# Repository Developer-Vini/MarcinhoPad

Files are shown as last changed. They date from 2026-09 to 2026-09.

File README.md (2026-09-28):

# MarcinhoPad

Custom macropad designed for the Hack Club Hackpad program.

## Overview

MarcinhoPad is a compact macro keyboard built around a Seeed XIAO RP2040. It features 6 mechanical switches, a rotary encoder for volume control, and an OLED display for visual feedback.

## Requirements Compliance

- MCU: Seeed XIAO RP2040 (through-hole)
- PCB: 2-layer, under 100mm x 100mm
- Case: 3D-printed only, fits within 200x200x100mm
- Inputs: 6 switches + 1 encoder (7 total, under 16 limit)
- Firmware: KMK (CircuitPython)

## Screenshots

### PCB
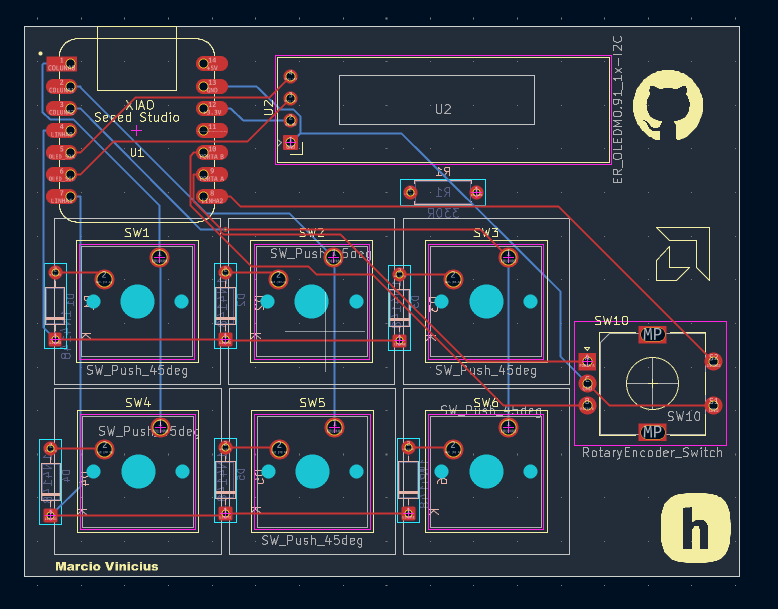
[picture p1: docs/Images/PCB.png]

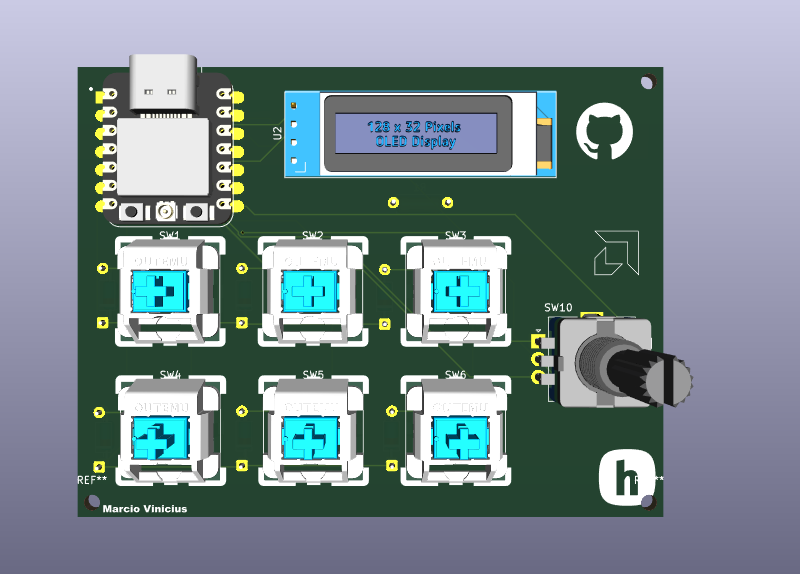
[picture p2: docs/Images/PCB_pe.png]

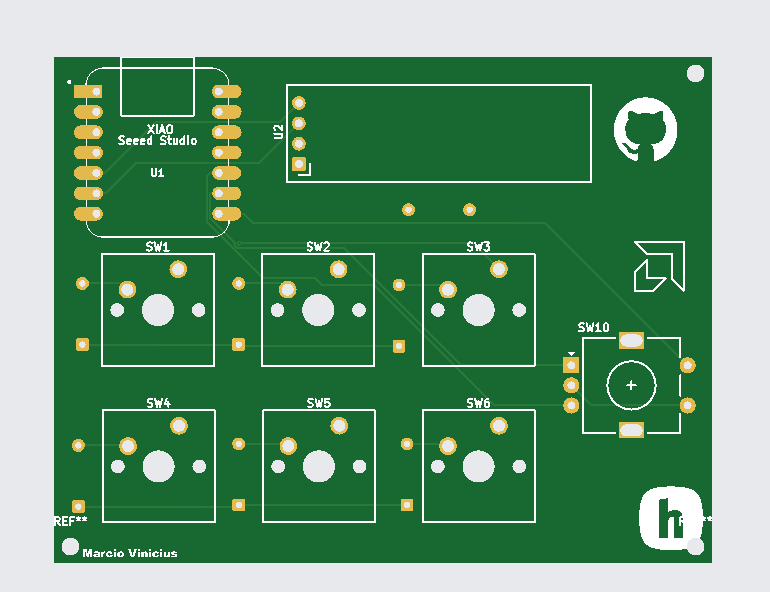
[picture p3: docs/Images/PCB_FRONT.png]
PCB_NOT

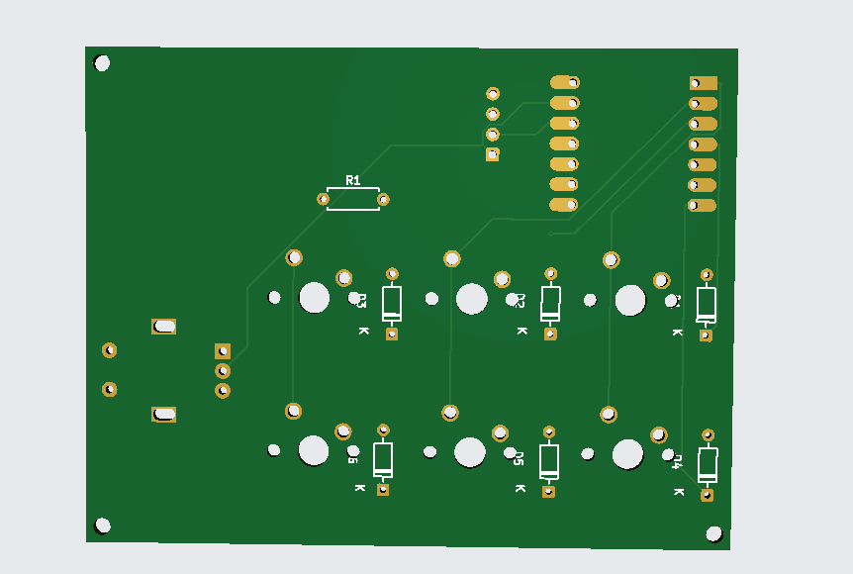
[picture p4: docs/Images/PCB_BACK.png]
PCB_BACK


### Schematic
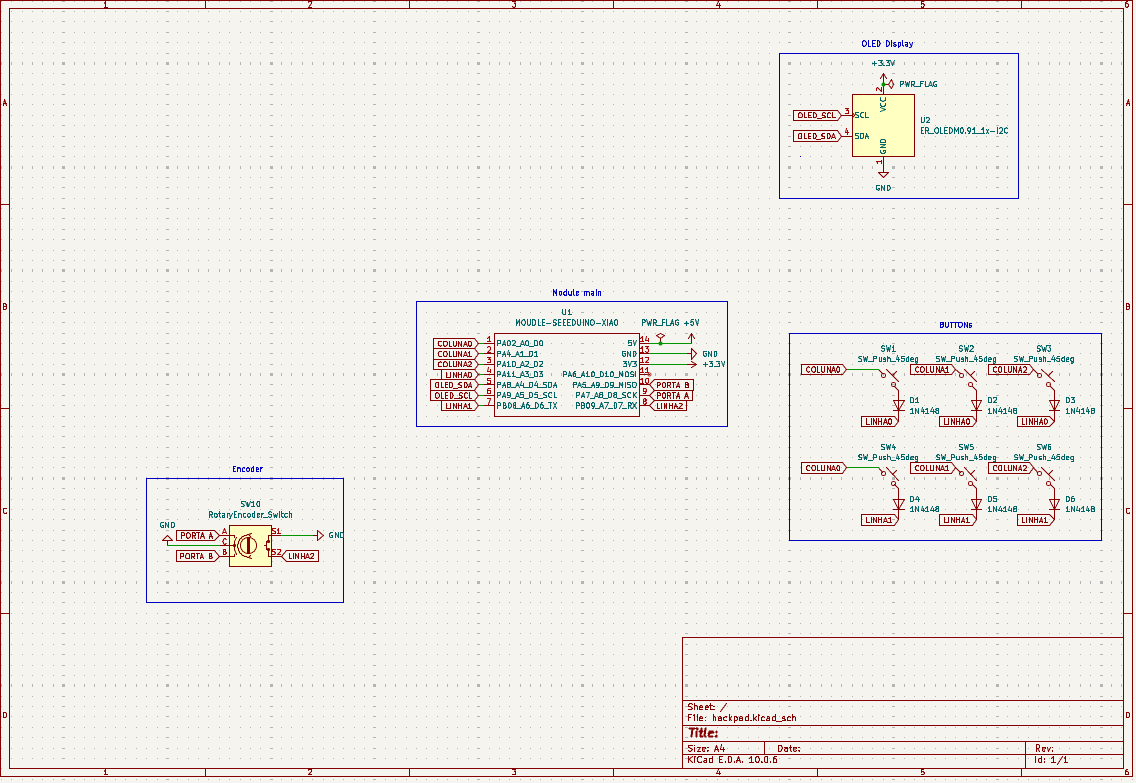
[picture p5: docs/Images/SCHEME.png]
Schematic


### Case
The case is 3D-printed in two parts (base + lid). See `production/case/` for STL files.

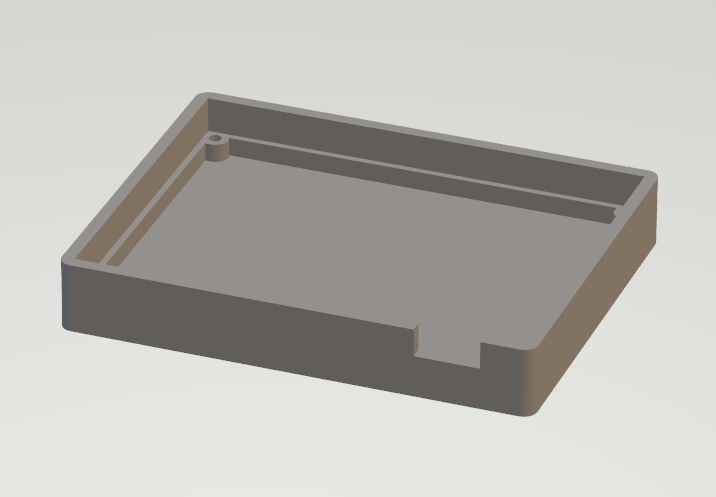
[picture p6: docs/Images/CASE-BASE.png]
BASE

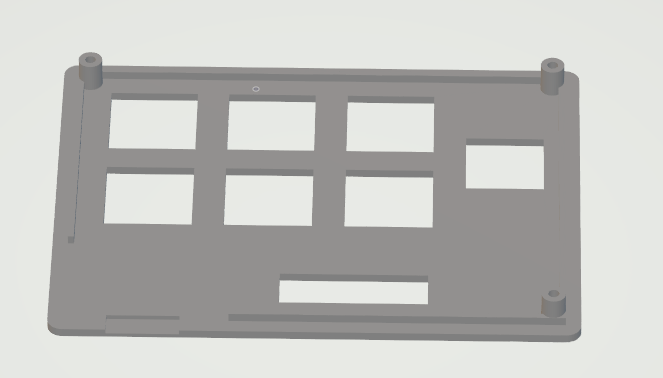
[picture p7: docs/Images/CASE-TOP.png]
TOPO


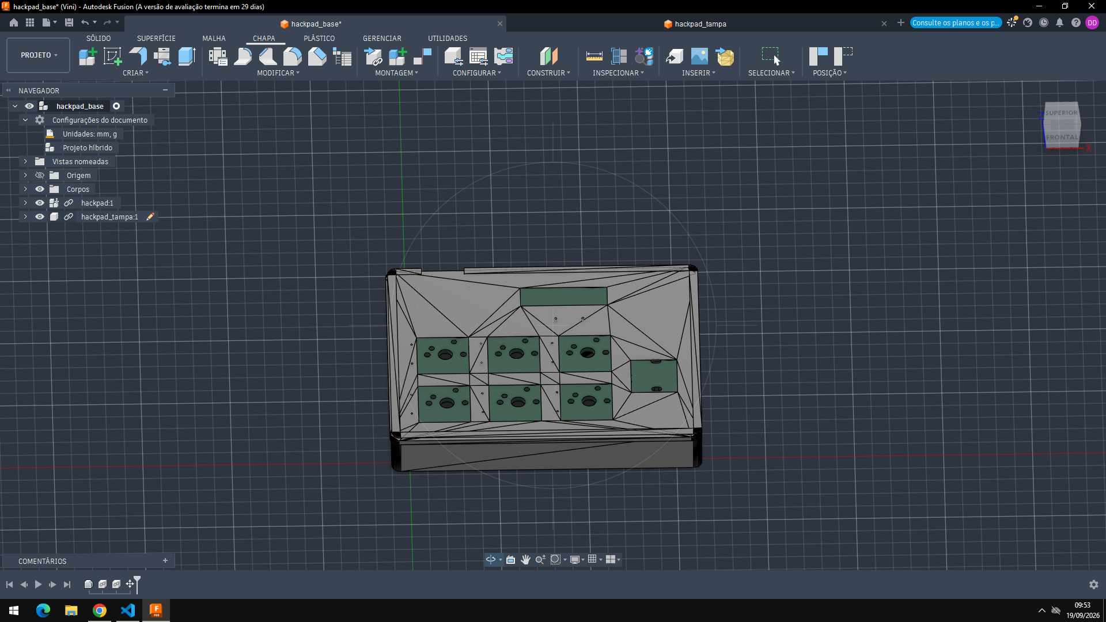
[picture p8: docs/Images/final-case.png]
FINAL-CASE


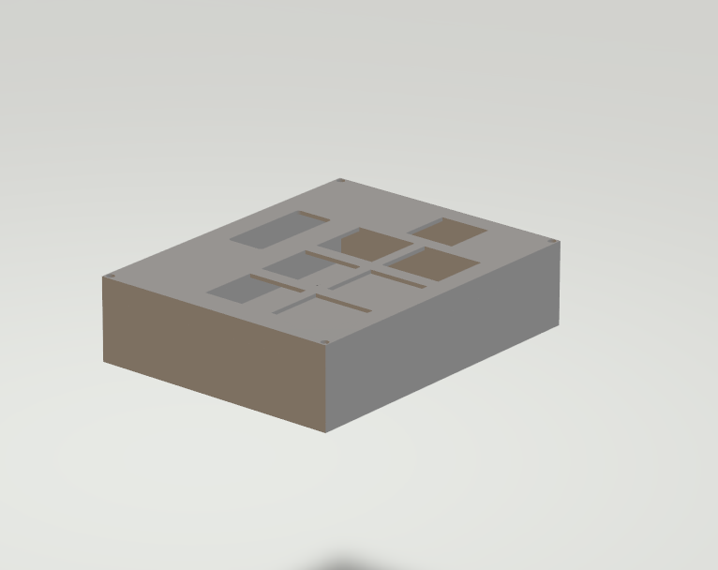
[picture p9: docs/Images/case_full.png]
case_full

I couldn't place the 3D model of the PCB with the components inside the case because I wasn't able to export the 3D models in KiCad.

# Bill of Materials

| Designator | Quantity | Value | Footprint | Part Number |
|---|---|---|---|---|
| U1 | 1 | Seeed XIAO RP2040 | XIAO-Generic-Hybrid-14P-2.54-21X17.8MM | Seeed XIAO RP2040 |
| U2 | 1 | 0.91" OLED SSD1306 | ER_OLEDM0.91_1x-I2C | 0.91" OLED I2C |
| SW1, SW2, SW3, SW4, SW5, SW6 | 6 | Tactile Switch 45° | SW_Cherry_MX_1.00u_PCB | Kailh Choc / compatible |
| SW10 | 1 | Rotary Encoder | RotaryEncoder_Alps_EC11E-Switch_Vertical_H20mm | Alps EC11E |
| D1, D2, D3, D4, D5, D6 | 6 | 1N4148 Diode | D_DO-35_SOD27_P7.62mm_Horizontal | 1N4148 |
| R1 | 1 | 330Ω Resistor | R_Axial_DIN0207_L6.3mm_D2.5mm_P7.62mm_Horizontal | 330Ω |

## Assembly Notes

- U1 (XIAO RP2040) is the main MCU, flashed with KMK firmware
- U2 (OLED) connects via I2C on D4 (SDA) and D5 (SCL)
- D1-D6 provide reverse polarity protection for switch matrix
- R1 is a current-limiting resistor for the OLED or indicator LED
- SW1-SW6 are the 6 key switches
- SW10 is the rotary encoder with integrated push button

## Firmware

The firmware is written in KMK for CircuitPython.

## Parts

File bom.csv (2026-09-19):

Designator | Footprint | Quantity | Value | LCSC Part #
D1, D2, D3, D4, D5, D6 | D_DO-35_SOD27_P7.62mm_Horizontal | 6 | 1N4148
R1 | R_Axial_DIN0207_L6.3mm_D2.5mm_P7.62mm_Horizontal | 1 | 330R
SW1, SW2, SW3, SW4, SW5, SW6 | SW_Cherry_MX_1.00u_PCB | 6 | SW_Push_45deg
SW10 | RotaryEncoder_Alps_EC11E-Switch_Vertical_H20mm | 1 | RotaryEncoder_Switch
U1 | XIAO-Generic-Hybrid-14P-2.54-21X17.8MM | 1 | MOUDLE-SEEEDUINO-XIAO
U2 | ER_OLEDM0.91_1x-I2C | 1 | ER_OLEDM0.91_1x-I2C

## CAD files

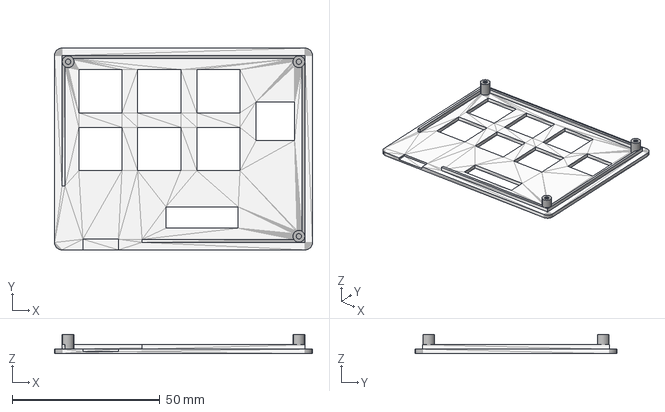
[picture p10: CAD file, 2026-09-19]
CAD/hackpad_tampa.step
87.2 x 68.2 x 6.50 mm

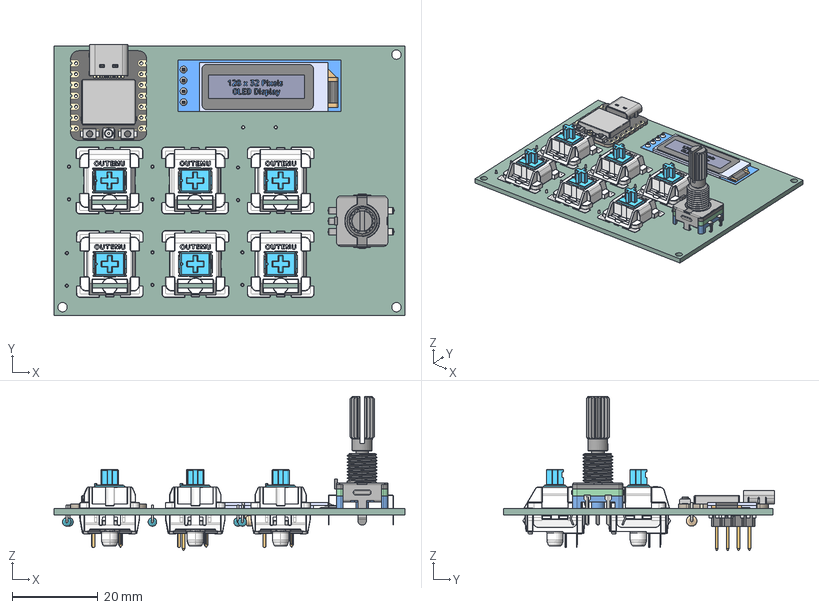
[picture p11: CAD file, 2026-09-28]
PCB/hackpad.step
82.0 x 63.4 x 36.0 mm
BOSS-EXTRUDE14_8_
BOSS-EXTRUDE7_4_
BOSS-EXTRUDE7_3_
BOSS-EXTRUDE14_4_
BOSS-EXTRUDE14_2_
BOSS-EXTRUDE14_11_
BOSS-EXTRUDE7_7_
BOSS-EXTRUDE14_9_
BOSS-EXTRUDE14_3_
BOSS-EXTRUDE14_7_
MIRROR2
BOSS-EXTRUDE14_5_
BOSS-EXTRUDE14_12_
BOSS-EXTRUDE7_8_
BOSS-EXTRUDE7_1_
BOSS-EXTRUDE14_10_
BOSS-EXTRUDE7_9_
BOSS-EXTRUDE14_6_
BOSS-EXTRUDE14_1_
BOSS-EXTRUDE7_6_
BOSS-EXTRUDE7_2_
CUT-EXTRUDE5
BOSS-EXTRUDE7_5_
U.FL Connector v1
Button (1) x 2
Shield
BOTT x 6
PIN x 6
SPRIN x 6
CLICK x 6
RET x 6
TOP x 6
EC11_Rotary_Encoder_Switched
Board_001
1x4 Male Header_001
0603 Capacitor_001
0603 Capacitor_002
0603 Capacitor_003
0603 Capacitor_004
0603 Capacitor_005
0603 Capacitor_006
0603 Capacitor_007
0603 Capacitor_008
0603 Resistor_001
0603 Resistor_002
0603 Resistor_003
0603 Resistor_004
0603 Resistor_005
Surface Mount Transistor_001
D_DO-35_SOD27_P7.62mm_Horizontal x 6
R_Axial_DIN0207_L63mm_D25mm_P762mm_Horizontal
hackpad_PCB

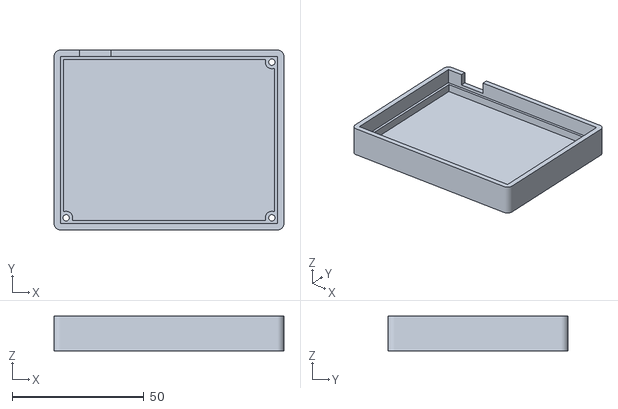
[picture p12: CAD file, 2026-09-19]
production/case/hackpad_base.stl
87.2 x 68.2 x 13.1

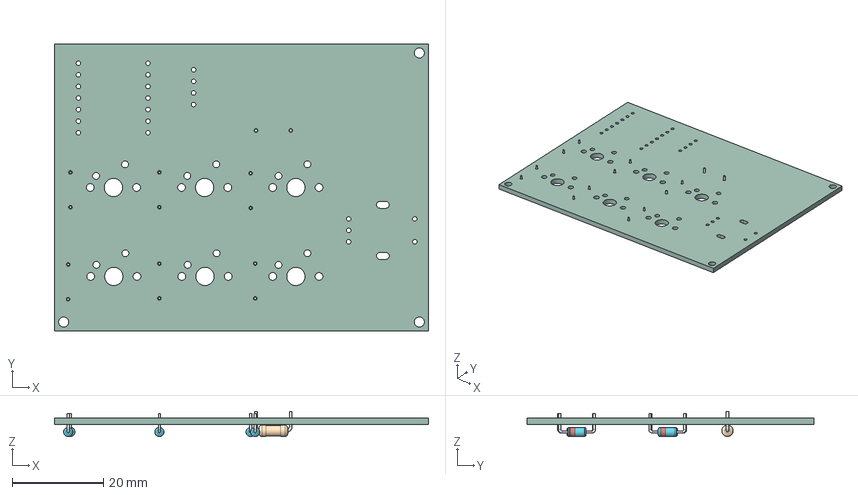
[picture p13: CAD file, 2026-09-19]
CAD/hackpad.step
82.0 x 63.0 x 5.51 mm
D_DO-35_SOD27_P7.62mm_Horizontal x 6
R_Axial_DIN0207_L63mm_D25mm_P762mm_Horizontal
hacA9D7_PCB

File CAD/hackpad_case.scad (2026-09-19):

// ============================================================
//  HACKPAD CASE  -  base + tampa (6 teclas MX 3x2, encoder EC11,
//  OLED 0.91", XIAO)   |   PCI 82 x 63 mm
//
//  Origem (0,0) = canto INFERIOR ESQUERDO da PCI, vista de cima
//  (mesma orientacao do print do KiCad). Unidades: mm.
//  Z = altura a partir do fundo da caixa.
//
//  Para gerar: mude PART abaixo e exporte (F6, depois F7 = STL).
// ============================================================

PART = "print";   // "print" | "base" | "lid" | "test_plate" | "assembly"

// ---------------- PCI ----------------
pcb_w = 82;        // X
pcb_h = 63;        // Y
pcb_t = 1.6;       // espessura

// ---------------- CAIXA ----------------
clear      = 0.2;  // folga entre PCI e parede (por lado)
wall       = 2.4;  // parede
floor_t    = 3.0;  // fundo
standoff_h = 3.5;  // vao sob a PCI (pinos dos switches + diodos)
gap_h      = 5.0;  // topo da PCI -> parte de baixo da tampa (padrao MX)
lid_t      = 1.5;  // espessura da tampa (1,5 = padrao pra placa de switch MX)
corner_r   = 2.5;  // raio dos cantos externos
ledge_w    = 1.0;  // faixa da borda da PCI que apoia na base

// ---------------- PARAFUSOS M2 (3 furos da PCI) ----------------
// Parafuso entra POR BAIXO: cabeca no fundo da base, rosca na tampa.
holes      = [[2, 2], [80, 2], [80, 61]];
m_d        = 2.4;  // furo passante na base
cb_d       = 4.4;  // rebaixo da cabeca
cb_depth   = 2.0;  // profundidade do rebaixo da cabeca
standoff_d = 5.0;  // pilarete da base
pillar_d   = 4.0;  // pilarete da tampa (nao passa da borda da PCI)
pilot_d    = 1.8;  // furo-piloto na tampa (rosca autoatarraxante M2)

// ---------------- TECLAS (centros dos switches) ----------------
key_x  = [12.9, 32.8, 52.8];   // colunas SW1/SW4, SW2/SW5, SW3/SW6
key_y  = [31.5, 12.0];         // fila de cima, fila de baixo
sw_cut = 14.6;                 // furo quadrado (14,0 + folga)

// ---------------- ENCODER (SW10) ----------------
enc_x   = 72.05;
enc_y   = 22.1;
enc_win = 13.0;   // janela quadrada: o corpo do EC11 (12 x 12) passa por ela

// ---------------- OLED 0.91" ----------------
oled_x = 47.3;
oled_y = 54.65;
oled_w = 24.4;    // area ativa 22,4 + margem
oled_h = 7.2;     // area ativa 5,6 + margem

// ---------------- USB-C (parede de cima) ----------------
usb_x = 13.0;
usb_w = 12.0;     // largura do recorte
usb_h = 6.0;      // altura do recorte
usb_z = 2.8;      // altura do centro do conector acima do topo da PCI

// ---------------- ENCAIXE DA TAMPA ----------------
lip_gap = 0.15;   // folga do rebordo da tampa dentro da parede
lip_t   = 1.0;    // espessura do rebordo
lip_h   = 1.5;    // quanto o rebordo desce

// ============ Derivados (nao precisa mexer) ============
z_pcb_bot = floor_t + standoff_h;
z_pcb_top = z_pcb_bot + pcb_t;
z_lid_bot = z_pcb_top + gap_h;
z_lid_top = z_lid_bot + lid_t;

ox0 = -(clear + wall);          ox1 = pcb_w + clear + wall;
oy0 = -(clear + wall);          oy1 = pcb_h + clear + wall;
px0 = -clear;                   py0 = -clear;
pw  = pcb_w + 2 * clear;        ph  = pcb_h + 2 * clear;

// ---------------- helpers ----------------
module rrect(x0, y0, x1, y1, r, h) {
    translate([x0 + r, y0 + r, 0])
        linear_extrude(h)
            offset(r = r, $fn = 48) square([x1 - x0 - 2 * r, y1 - y0 - 2 * r]);
}

module usb_cut() {
    translate([usb_x - usb_w / 2, pcb_h - 1.0, z_pcb_top + usb_z - usb_h / 2])
        cube([usb_w, 10, usb_h]);
}

// recortes da tampa (2D): teclas, encoder, OLED
module cutouts_2d() {
    for (x = key_x, y = key_y)
        translate([x - sw_cut / 2, y - sw_cut / 2]) square(sw_cut);
    translate([enc_x - enc_win / 2, enc_y - enc_win / 2]) square(enc_win);
    translate([oled_x - oled_w / 2, oled_y - oled_h / 2]) square([oled_w, oled_h]);
}

// ---------------- BASE ----------------
module base() {
    difference() {
        union() {
            // casca com rebaixo
            difference() {
                rrect(ox0, oy0, ox1, oy1, corner_r, z_lid_bot);
                translate([px0, py0, floor_t]) cube([pw, ph, z_lid_bot]);
            }
            // borda de apoio da PCI (perimetro)
            difference() {
                translate([px0, py0, floor_t - 0.01])
                    cube([pw, ph, standoff_h + 0.01]);
                translate([ledge_w, ledge_w, floor_t - 1])
                    cube([pcb_w - 2 * ledge_w, pcb_h - 2 * ledge_w, standoff_h + 3]);
            }
            // pilaretes
            for (h = holes)
                translate([h[0], h[1], floor_t - 0.01])
                    cylinder(d = standoff_d, h = standoff_h + 0.01, $fn = 48);
        }
        // furos + rebaixo da cabeca do parafuso
        for (h = holes) {
            translate([h[0], h[1], -1]) cylinder(d = m_d, h = z_pcb_bot + 2, $fn = 32);
            translate([h[0], h[1], -1]) cylinder(d = cb_d, h = cb_depth + 1, $fn = 32);
        }
        usb_cut();
    }
}

// ---------------- TAMPA (na posicao montada) ----------------
module lid() {
    difference() {
        union() {
            // placa da tampa
            translate([0, 0, z_lid_bot]) rrect(ox0, oy0, ox1, oy1, corner_r, lid_t);
            // rebordo de encaixe (nao passa pela area do XIAO)
            difference() {
                translate([0, 0, z_lid_bot - lip_h])
                    linear_extrude(lip_h + 0.01)
                        difference() {
                            translate([px0 + lip_gap, py0 + lip_gap])
                                square([pw - 2 * lip_gap, ph - 2 * lip_gap]);
                            translate([px0 + lip_gap + lip_t, py0 + lip_gap + lip_t])
                                square([pw - 2 * (lip_gap + lip_t), ph - 2 * (lip_gap + lip_t)]);
                        }
                translate([-6, 44, z_lid_bot - lip_h - 1]) cube([33, 30, lip_h + 2]);
            }
            // pilaretes que descem ate a PCI
            for (h = holes)
                translate([h[0], h[1], z_pcb_top])
                    cylinder(d = pillar_d, h = gap_h + 0.01, $fn = 40);
        }
        // furo-piloto (cego, nao aparece em cima)
        for (h = holes)
            translate([h[0], h[1], z_pcb_top - 0.01])
                cylinder(d = pilot_d, h = gap_h + 0.5, $fn = 24);
        // teclas, encoder, OLED
        translate([0, 0, z_lid_bot - 2]) linear_extrude(lid_t + 4) cutouts_2d();
        usb_cut();
    }
}

// tampa virada (face de cima na mesa), pronta pra imprimir sem suporte
module lid_flipped() {
    translate([0, oy0 + oy1, z_lid_top]) rotate([180, 0, 0]) lid();
}
// mesma coisa, mas deslocada pra ficar ao lado da base na mesa
module lid_print() {
    translate([0, (oy1 - oy0) + 8, 0]) lid_flipped();
}

// ---------------- PLACA DE TESTE ----------------
// Impressao rapida (~10 min) so pra conferir os furos ANTES de soldar:
// encaixe os switches nela e na PCI e veja se tudo entra sem forcar.
module test_plate() {
    linear_extrude(1.2)
        difference() {
            translate([-2, -2]) square([pcb_w + 4, pcb_h + 4]);
            cutouts_2d();
            for (h = holes) translate(h) circle(d = m_d, $fn = 32);
        }
}

// ---------------- SAIDA ----------------
if (PART == "base") base();
else if (PART == "lid") lid_flipped();
else if (PART == "test_plate") test_plate();
else if (PART == "assembly") {
    base();
    color("silver") lid();
    %translate([0, 0, z_pcb_bot]) cube([pcb_w, pcb_h, pcb_t]);
}
else { base(); lid_print(); }

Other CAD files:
CAD/hackpad_base.step
production/case/hackpad_tampa.stl
production/stl/hackpad_tampa.stl

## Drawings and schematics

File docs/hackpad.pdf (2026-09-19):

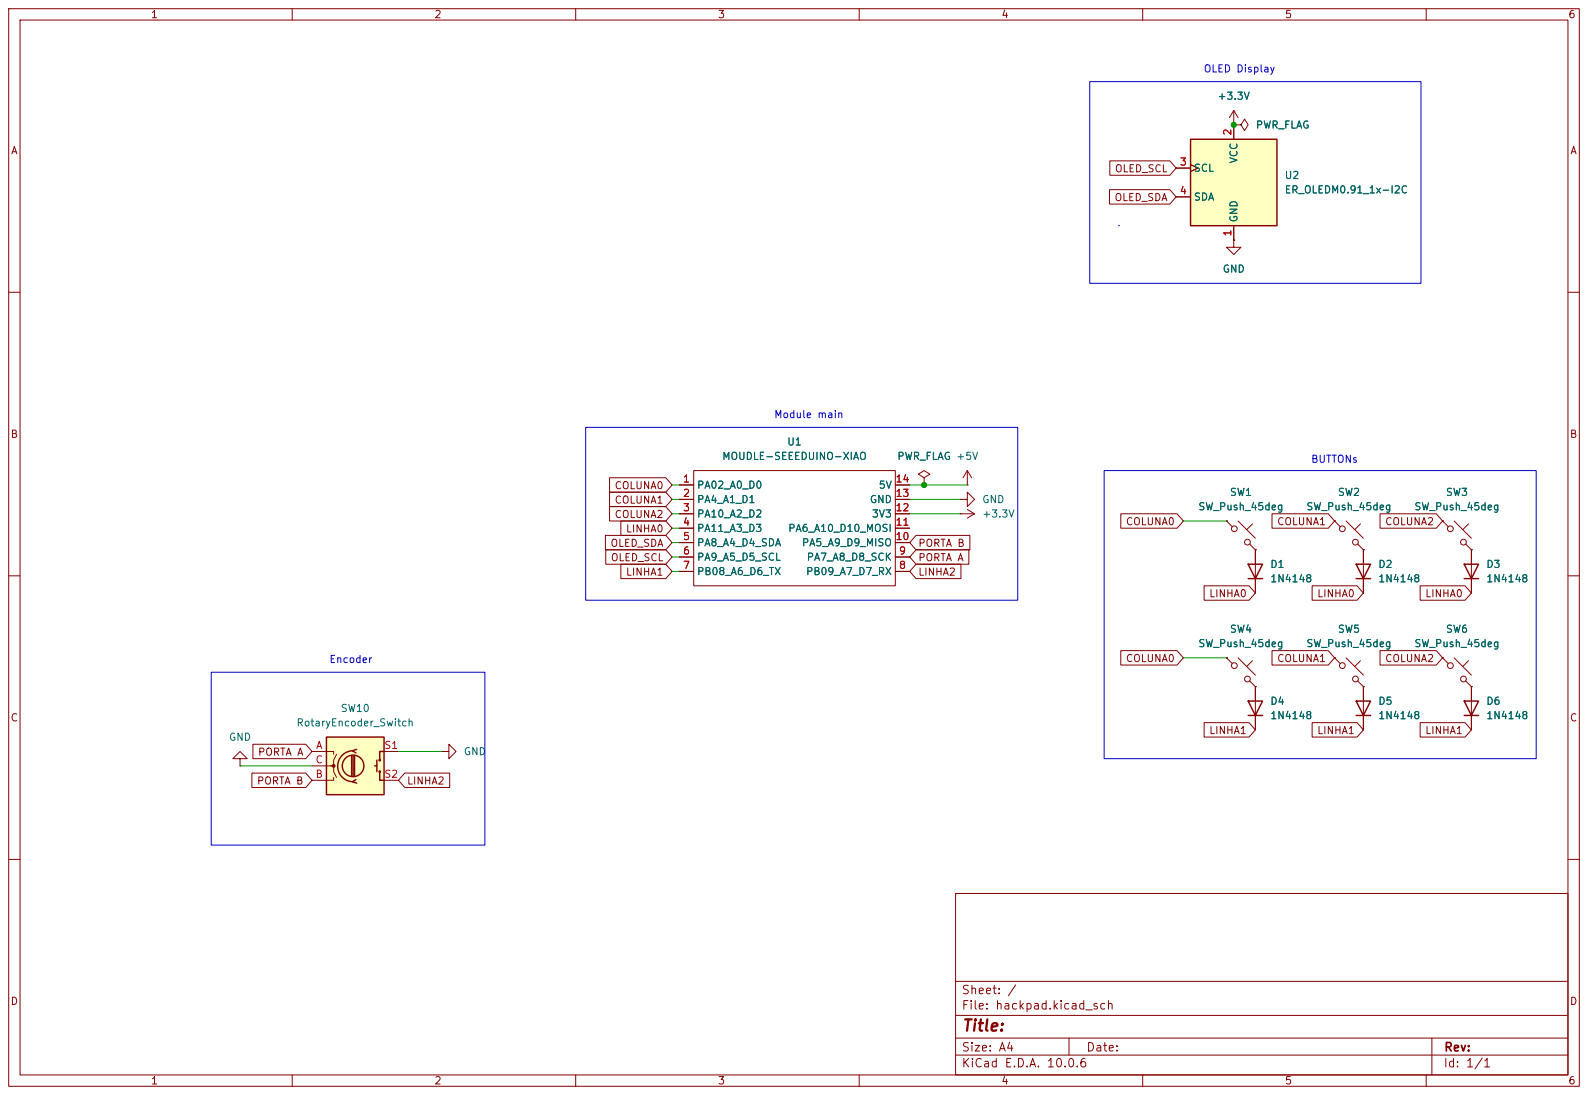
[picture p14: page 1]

Size: A4 | Rev:
KiCad E.D.A. 10.0.6 | Id: 1/1

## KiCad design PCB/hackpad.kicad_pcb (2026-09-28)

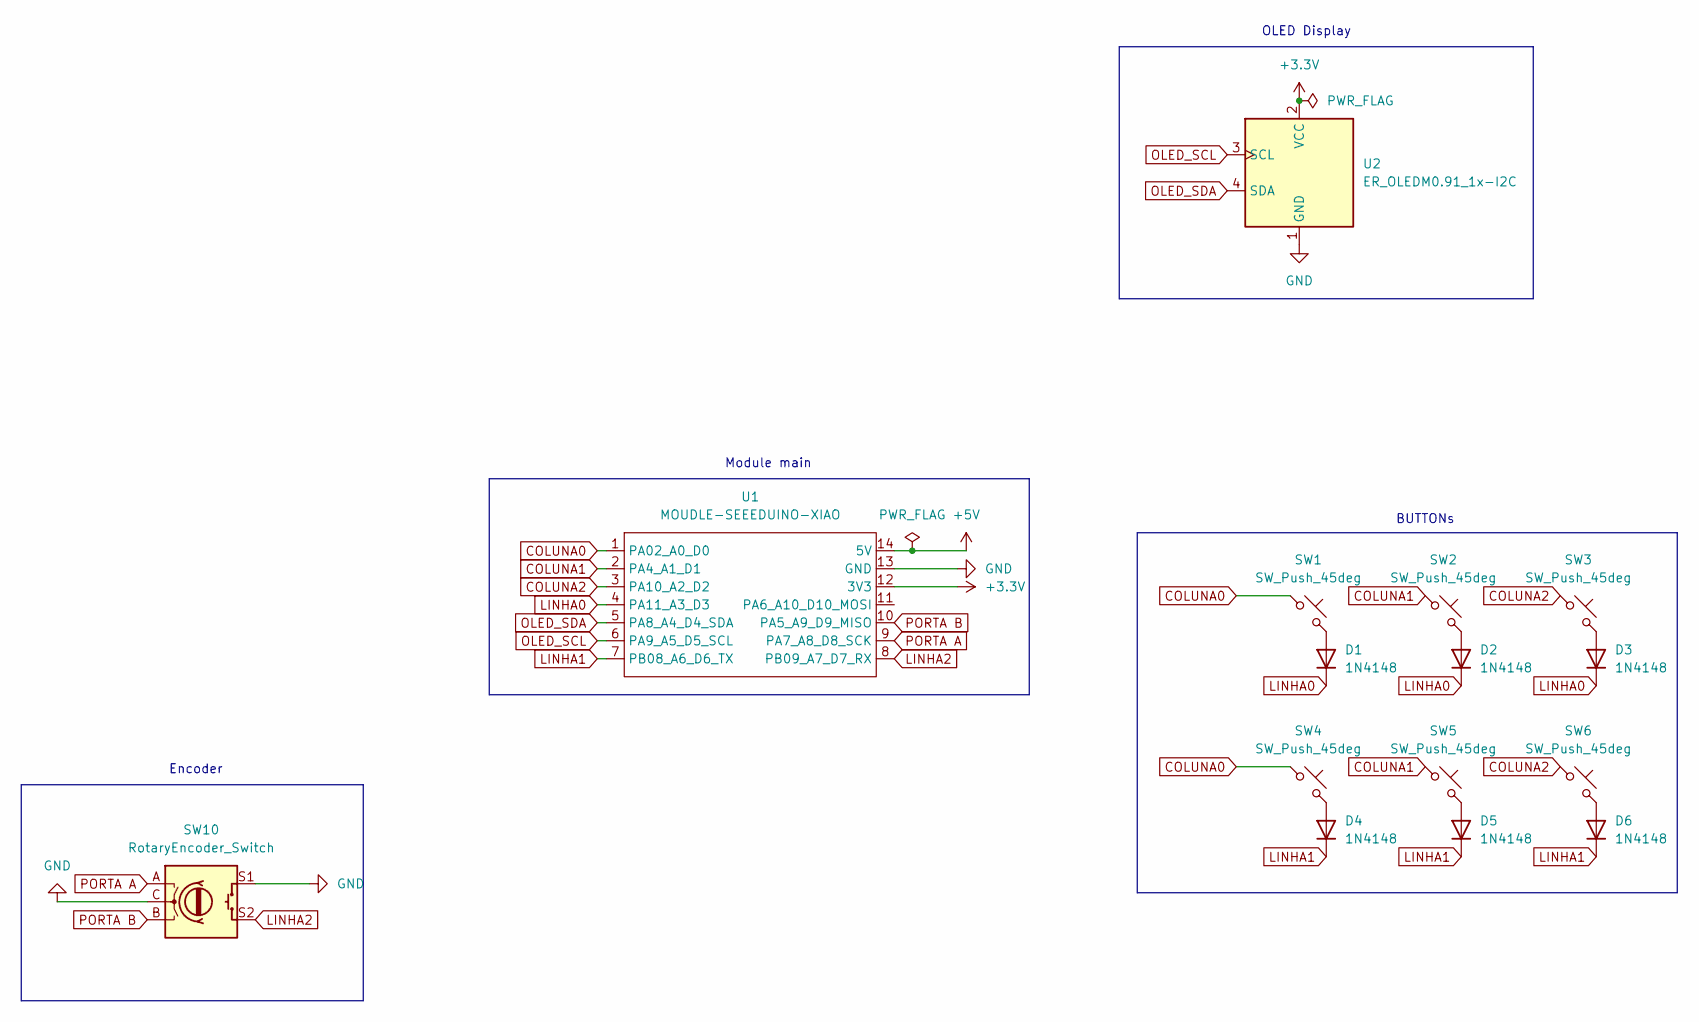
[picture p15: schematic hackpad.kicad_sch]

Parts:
D1, D2, D3, D4, D5, D6: 1N4148; D_DO-35_SOD27_P7.62mm_Horizontal
SW1, SW2, SW3, SW4, SW5, SW6: SW_Push_45deg; SW_Cherry_MX_1.00u_PCB
SW10: RotaryEncoder_Switch; RotaryEncoder_Alps_EC11E-Switch_Vertical_H20mm
U1: MOUDLE-SEEEDUINO-XIAO; XIAO-Generic-Hybrid-14P-2.54-21X17.8MM
U2: ER_OLEDM0.91_1x-I2C

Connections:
+3.3V: U1.12 (3V3), U2.2 (VCC)
+5V: U1.14 (5V)
COLUNA0: SW1.1, SW4.1, U1.1 (PA02_A0_D0)
COLUNA1: SW2.1, SW5.1, U1.2 (PA4_A1_D1)
COLUNA2: SW3.1, SW6.1, U1.3 (PA10_A2_D2)
GND: SW10.C, SW10.S1, U1.13 (GND), U2.1 (GND)
LINHA0: D1.1 (K), D2.1 (K), D3.1 (K), U1.4 (PA11_A3_D3)
LINHA1: D4.1 (K), D5.1 (K), D6.1 (K), U1.7 (PB08_A6_D6_TX)
LINHA2: SW10.S2, U1.8 (PB09_A7_D7_RX)
unnamed: D1.2 (A), SW1.2
unnamed: D2.2 (A), SW2.2
unnamed: D3.2 (A), SW3.2
unnamed: D4.2 (A), SW4.2
unnamed: D5.2 (A), SW5.2
unnamed: D6.2 (A), SW6.2
OLED_SCL: U1.6 (PA9_A5_D5_SCL), U2.3 (SCL)
OLED_SDA: U1.5 (PA8_A4_D4_SDA), U2.4 (SDA)
PORTA A: SW10.A, U1.9 (PA7_A8_D8_SCK)
PORTA B: SW10.B, U1.10 (PA5_A9_D9_MISO)

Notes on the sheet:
Encoder
Module main
OLED Display
BUTTONs

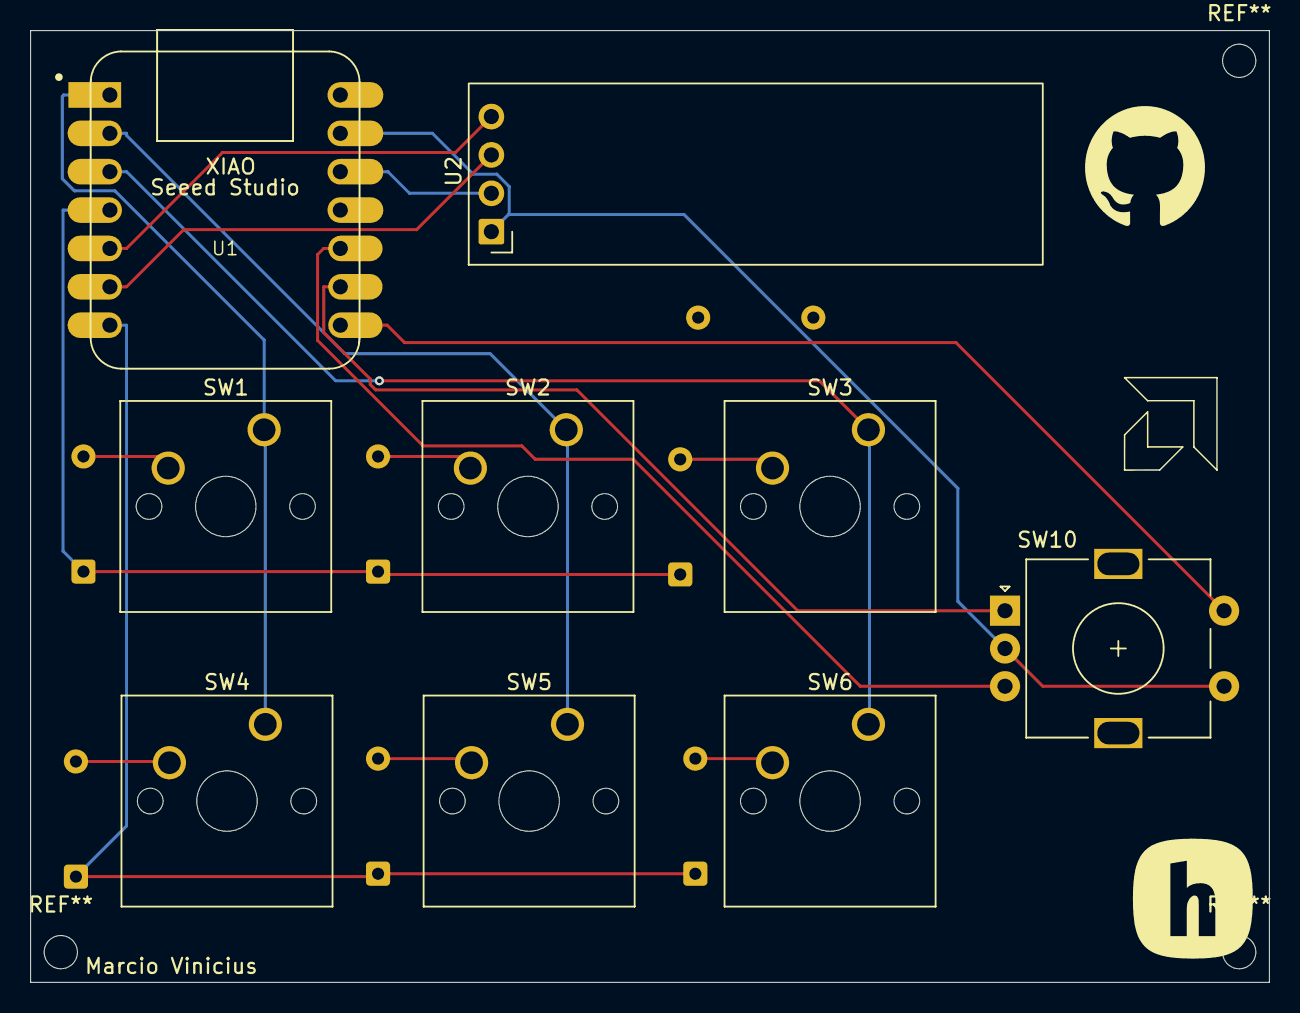
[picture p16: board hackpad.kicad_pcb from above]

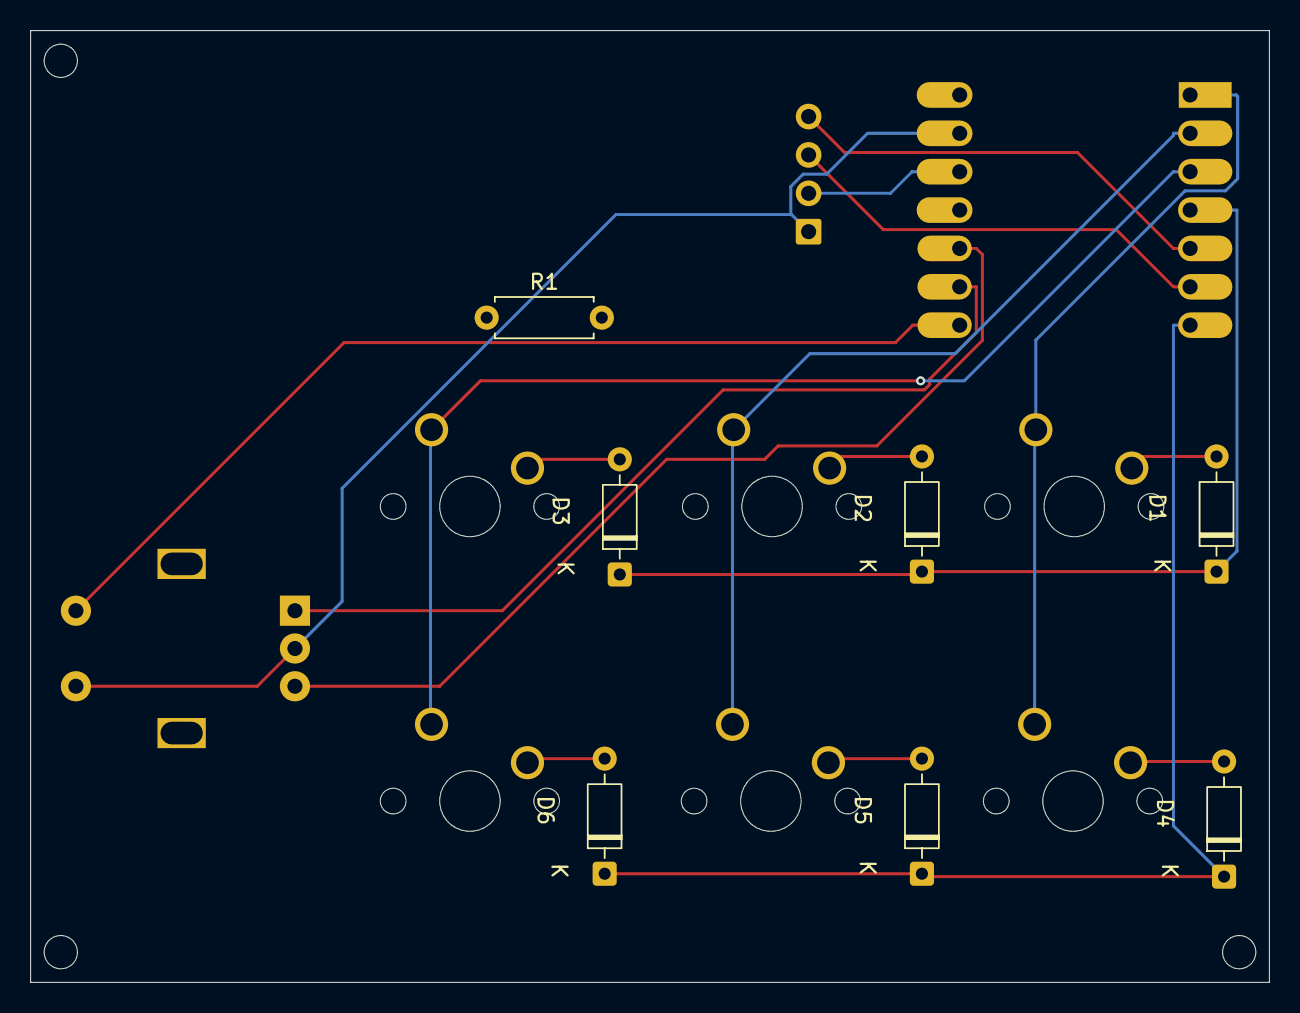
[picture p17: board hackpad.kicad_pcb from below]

Board: 2 copper layers, 82.0 x 63.0 mm, 16 parts (7 on the bottom side), 18 nets.

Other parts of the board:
R1: 330R; R_Axial_DIN0207_L6.3mm_D2.5mm_P7.62mm_Horizontal

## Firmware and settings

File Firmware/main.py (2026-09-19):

from kmk.extensions.media_keys import MediaKeys

from board_config import get_keyboard
from keymap import get_keymap
from encoder import get_encoder
from display import get_display


def main():
    keyboard = get_keyboard()
    keyboard.keymap = get_keymap()

    keyboard.extensions.append(MediaKeys())

    encoder = get_encoder()
    keyboard.modules.append(encoder)

    display = get_display()
    keyboard.extensions.append(display)

    keyboard.go()


if __name__ == "__main__":
    main()

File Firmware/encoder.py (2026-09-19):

import board

from kmk.keys import KC
from kmk.modules.encoder import EncoderHandler


def get_encoder():
    # A -> PORTA A -> D8
    # B -> PORTA B -> D9
    # C -> GND

    # S1 -> GND
    # S2 -> LINHA2 -> D7

    encoder_handler = EncoderHandler()

    encoder_handler.pins = (
        (
            board.D8,
            board.D9,
            board.D7,
            False,  # não inverter
        )
    )

    # vol -
    # vol +
    # press mute
    encoder_handler.map = [
        (
            (
                KC.VOLD,
                KC.VOLU,
                KC.MUTE,
            ),
        ),
    ]

    return encoder_handler

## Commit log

2026-09-19 chore: complete final project submission
    [bom.csv, designators.csv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]
2026-09-19 feat(readme.md): Adding an image of the assembled case with PCB.
2026-09-28 docs(readme.md) updating the README and adding more images to the project
    [hackpad.kicad_pcb, hackpad.step]
